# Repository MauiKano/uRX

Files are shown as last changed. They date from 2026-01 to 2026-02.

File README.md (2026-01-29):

Hybrid NAVTEX & Wideband Receiver (ESP32 + Tayloe Mixer + Si4732)
Overview
This project is a high-performance, dual-path radio receiver designed for the ESP32 platform. It combines a traditional digital "Radio-on-a-Chip" (Si4732) with a high-sensitivity, software-defined Tayloe Quadrature Product Detector (QPD). The design is specifically optimized for the reception and decoding of NAVTEX signals at 518 kHz, utilizing a professional-grade analog signal chain and high-resolution external ADCs.
Key Features
1. Dual Receiver Architecture

    Path A (SDR): A high-linearity Tayloe Mixer (using the CBT3253 bus switch) for I/Q sampling. This path is intended for precision DSP decoding of weak digital modes like NAVTEX.
    Path B (Digital): An Si4732-A10 all-in-one receiver for general-purpose listening (AM/FM/SW/LW) and RDS data acquisition.

2. High-End Analog Signal Chain

    Active Antenna Splitter: An OPA2690 high-speed current-feedback op-amp serves as an active buffer/splitter, providing high isolation between the two receiver paths without signal loss.
    Post-Mixer Amplification: A LM4562 ultra-low noise, high-fidelity audio operational amplifier provides 33.4 dB of gain (Gain=47) to the I/Q signals.
    Optimized Filtering: Integrated active low-pass filtering with a 2.8 kHz cutoff, specifically tuned to maximize the SNR for NAVTEX/SITOR-B signals.
    Ultra-Stable Reference: A precision LM4040 (2.5V) shunt reference provides a clean virtual ground for the analog stages, ensuring maximum dynamic range and rejection of power supply noise.

3. Precision Clocking & Digitization

    Clock Generation: An Si5351A triple clock generator provides the quadrature sampling clock for the Tayloe mixer and a dedicated low-jitter master clock for the ADC.
    External ADC: Instead of the noisy internal ESP32 ADC, this design uses the PCM1808 (24-bit, 99dB SNR). It interfaces via I2S, providing a transparent digital stream to the ESP32 for software demodulation.

4. EMI/EMC Optimized Layout

    Power Isolation: Independent Ferrite Bead filtering for every major IC to prevent digital switching noise from the ESP32 and Si5351 from polluting the analog front-end.
    Ground Management: Strict separation of analog and digital ground paths, joined at a single star-point under the ADC to minimize ground loops.

Technical Specifications

    Primary Frequency: 518 kHz (NAVTEX)
    Mixer Type: Quadrature Sampling Detector (Tayloe)
    ADC Resolution: 24-Bit I2S (PCM1808)
    Processor: ESP32 (Dual-Core 240 MHz)
    I/Q Bandwidth: ~3 kHz (Optimized for digital modes)

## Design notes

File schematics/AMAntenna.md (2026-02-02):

# uRX Antenna Subsystem: Navtex Dual-Band Ferrite Antenna

This document specifies the design and construction of the high-performance magnetic loopstick antenna for the **uRX** handheld receiver, optimized for **490 kHz** and **518 kHz** Navtex reception.

## Technical Specifications

| Parameter | Specification | Notes |
|---|---|---|
| **Primary Frequency** | 518 kHz | International Navtex (English) |
| **Secondary Frequency** | 490 kHz | Local Navtex (National languages) |
| **Antenna Type** | High-Q Magnetic Loopstick  | Optimized for MF (Medium Frequency) |
| **Target Inductance** | 330 µH | Matches [Si4732 AMI](https://www.silabs.com) requirements |
| **Rod Material** | NiZn Ferrite (Mix 61) | Low-loss at 500 kHz ([Fair-Rite Type 61](https://fair-rite.com)) |
| **Rod Dimensions** | 10 mm x 80 mm | Balanced for handheld portability |
| **Conductor Type** | 40/46 Litz Wire | Minimizes skin effect, ensures high Q |

## Winding & Construction

To achieve the target inductance of **330 µH** on the specified 10 mm rod, follow these construction steps:

*   **Turn Count:** Approximately **66 turns** (single-layer solenoid).
*   **Winding Method:** Wind the Litz wire tightly on a movable paper or plastic sleeve.
*   **Inductance Tuning:** Slide the coil toward the center of the rod to increase inductance, or toward the ends to decrease it.
*   **Resonance Tuning:**
    *   **Band Center:** 504 kHz.
    *   **Fixed Capacitor:** 270 pF (**NP0/C0G** dielectric for thermal stability).
    *   **Trimmer:** 10–60 pF parallel trimmer for fine-tuning the peak resonance.

## Interface & System Integration

*   **Buffer Stage:** The antenna feeds the [Texas Instruments OPA2211](https://www.ti.com) (U11).
*   **Input Impedance ($Z_{in}$):** Maintained at **100 kΩ** via the bias resistor (**R2**) to prevent damping of the tuned circuit.
*   **Isolation:** The dual-opamp configuration provides independent signal paths for the **Tayloe Mixer** and the **Si4732** tuner, preventing local oscillator (LO) leakage.
*   **Expected Performance:** A Q-factor of **>150**, providing excellent narrowband selectivity and rejection of out-of-band noise (e.g., from the ESP32-C3 digital lines).

---
*Documentation generated for the uRX Project - 2026*

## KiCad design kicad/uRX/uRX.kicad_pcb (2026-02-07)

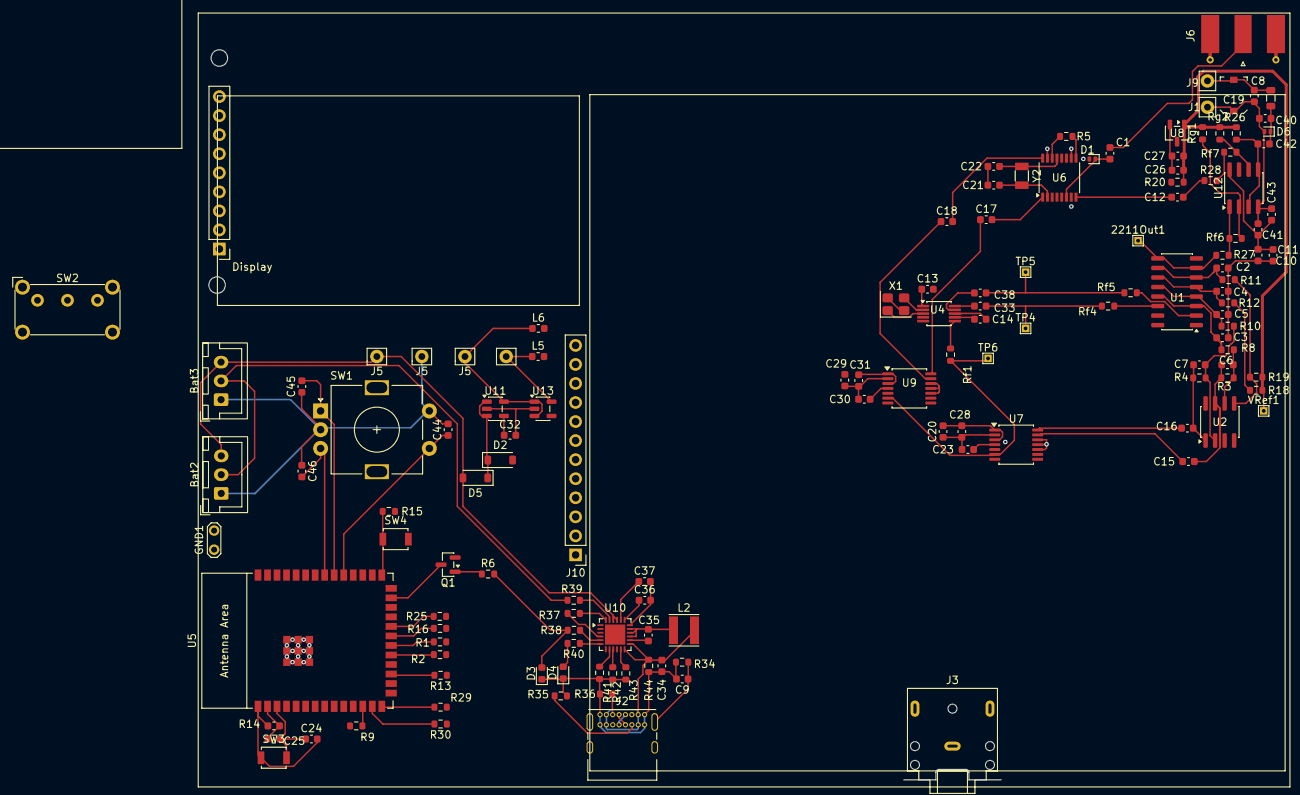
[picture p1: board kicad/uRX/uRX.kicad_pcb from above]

Board: 2 copper layers, 142 parts (0 on the bottom side), 91 nets.

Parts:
2211Out1: TestPoint; TestPoint_THTPad_1.0x1.0mm_Drill0.5mm
Bat2, Bat3: JST-XH; JST_XH_B3B-XH-A_1x03_P2.50mm_Vertical
C1, C40: 100p; C_0603_1608Metric
C2, C3, C4, C5: 220n; C_0603_1608Metric
C6, C7: 1.2n; C_0603_1608Metric
C8: 270p; C_0603_1608Metric
C9: 4.7n; C_0603_1608Metric
C10, C41: 2.2u; C_0603_1608Metric
C11, C12, C13, C14, C23, C26, C28, C30, C31, C35, C42, C43, C44, C45, C46: 100n; C_0603_1608Metric
C15, C16, C17, C18: 4.7u; C_0603_1608Metric
C19: 10p-60p; C_Trimmer_Murata_TZC3
C20, C27, C29, C34, C36, C37: 10u; C_0603_1608Metric
C21, C22: 22p; C_0603_1608Metric
C24: 1u; C_0603_1608Metric
C25: 47u; C_0603_1608Metric
C32, C33, C38: 10n; C_0603_1608Metric
D1, D6: PESD5V0L1ULD; D_SOD-882D
D2, D5: D_Schottky; D_SOD-123
D3, D4: LED_Small; LED_0603_1608Metric
Display: PinHeader_1x09_P2.54mm_Vertical
GND1: TestPoint_2Pole; TestPoint_2Pads_Pitch2.54mm_Drill0.8mm
J1: RF_AM_GND; Pin_D0.9mm_L10.0mm_W2.4mm_FlatFork
J2: C165948; USB_C_Receptacle_GCT_USB4085
J3: AudioJack2_Ground; Jack_3.5mm_CUI_SJ1-3523N_Horizontal
J5, J5#4: +5V; Pin_D0.9mm_L10.0mm_W2.4mm_FlatFork
J5#2: GND; Pin_D0.9mm_L10.0mm_W2.4mm_FlatFork
J5#3: Bat; Pin_D0.9mm_L10.0mm_W2.4mm_FlatFork
J6: U.FL; SMA_Molex_73251-1153_EdgeMount_Horizontal
J9: RF_AM__In; Pin_D0.9mm_L10.0mm_W2.4mm_FlatFork
J10: GPIO_A; PinHeader_1x12_P2.54mm_Vertical
L2: 2.2uH,3A; L_Taiyo-Yuden_NR-40xx
L4: 1uH,50mA; L_0805
L5, L6: Ferrite_perl; L_0603_1608Metric
M2, M2#2, M2#3, M2#4, M2#5, M2#6, M2#7: MountingHole_2.2mm_M2_DIN965
Q1: BC847; SOT-23
R1, R2, R16, R25, R27, R28, R29, R30: 22; R_0603_1608Metric
R3, R4, R18, R19: 47k; R_0603_1608Metric
R5, R14, R15: 10k; R_0603_1608Metric
R6: 10K; R_0603_1608Metric
R8, R10, R11, R12, R20: 1k; R_0603_1608Metric
R9, R13: 4.7K; R_0603_1608Metric
R26: 100k; R_0603_1608Metric
R34: 1M; R_0603_1608Metric
R35, R36, R44: 5.1K; R_0603_1608Metric
R37: 33k; R_0603_1608Metric
R38, R39, R40: 100; R_0603_1608Metric
R41, R42: 120K; R_0603_1608Metric
R43: 75k; R_0603_1608Metric
Rf1, Rf4, Rf5: 47; R_0603_1608Metric
Rf6, Rf7: 604; R_0603_1608Metric
Rg1, Rg2: 604; R_0603_1608Metric
SW1: RotaryEncoder_Switch; RotaryEncoder_Alps_EC11E-Switch_Vertical_H20mm
SW2: SW_DPDT_x2; SW_E-Switch_EG1224_SPDT_Angled
SW3: Reset; SW_SPST_B3U-1000P
SW4: Boot; SW_SPST_B3U-1000P
TP4: CLK0; TestPoint_THTPad_1.0x1.0mm_Drill0.5mm
TP5: CLK1; TestPoint_THTPad_1.0x1.0mm_Drill0.5mm
TP6: CLK2; TestPoint_THTPad_1.0x1.0mm_Drill0.5mm
U1: CBT3253; SO-16_3.9x9.9mm_P1.27mm
U2: LM4562; SOIC-8_3.9x4.9mm_P1.27mm
U4: Si5351A-B-GT; MSOP-10_3x3mm_P0.5mm
U5: ESP32-S3-WROOM-2
U6: Si4732-A10; SSOP-16_3.9x4.9mm_P0.635mm
U7, U9: PCM1808PWR; TSSOP-14_4.4x5mm_P0.65mm
U8: LM4040-2.5; SOT-23-3
U10: IP2326; QFN-24-1EP_4x4mm_P0.5mm_EP2.7x2.7mm
U11: LP2985-5.0; SOT-23-5
U12: OPA2211; SOIC-8_3.9x4.9mm_P1.27mm
U13: HT733333; SOT-23-5
VRef1: VRef; TestPoint_THTPad_1.0x1.0mm_Drill0.5mm
X1: X322525MOB4SI; Crystal_SMD_3225-4Pin_3.2x2.5mm
Y2: 32768kHz; Crystal_SMD_3215-2Pin_3.2x1.5mm

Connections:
+3.3V: C13.1, C14.1, C25.1, C30.2, J5.1, J10.10, L5.1, R5.1, R9.1, R13.1, R14.1, R15.1, U4.1 (VDD), U4.7 (VDDO), U5.2 (3V3), U6.14 (VDD), U9.4 (VDD), U13.5 (VOUT)
+3.3Vfiltered: C23.2, U7.4 (VDD)
+5V: C29.2, C31.2, J10.9, L6.1, SW2.2 (B), U9.1 (VREF), U9.3 (VCC), U13.1 (VIN), U13.3 (EN)
+5Vfiltered: C10.1, C11.1, C20.2, C28.2, C41.1, C43.1, R20.2, U1.16 (VCC), U7.1 (VREF), U7.3 (VCC), U12.8 (V+)
+VBatt: Bat2.3, Bat3.3, D5.2 (A), J5#3.1, U10.21 (VOUT), U10.22 (VOUT)
/I2S0_DOUT: J10.6, R16.1, U7.9 (DOUT)
/I2S1_DOUT: J10.7, R25.1, U9.9 (DOUT)
/I2S_BCK: J10.4, R1.1, U7.8 (BCK), U9.8 (BCK)
/I2S_LRCK: J10.5, R2.1, U7.7 (LRCK), U9.7 (LRCK)
/SCL: J10.2, R13.2, U4.4 (SCL), U5.17 (GPIO9/TOUCH9/ADC1_CH8/FSPIHD/SUBSPIHD), U6.11 (SCLK)
/SDA: J10.1, R9.2, U4.5 (SDA), U5.12 (GPIO8/TOUCH8/ADC1_CH7/SUBSPICS1), U6.12 (SDIO)
/VRev2.5: C26.1, C27.1, R18.2, R19.2, R20.1, R26.2, Rg1.2, Rg2.1, U8.1 (K), VRef1.1
ADC_SCKI: J10.3, Rf1.1, TP6.1, U5.18 (GPIO10/TOUCH10/ADC1_CH9/FSPICS0/FSPIIO4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), U7.6 (SCKI), U9.6 (SCKI)
Earth: D1.2 (A), U6.7 (RFGND)
GND: Bat2.1, Bat3.1, C2.2, C3.2, C4.2, C5.2, C8.2, C9.2, C10.2, C11.2, C13.2, C14.2, C19.1, C20.1, C21.1, C22.1, C23.1, C24.2, C25.2, C26.2, C27.2, C28.1, C29.1, C30.1, C31.1, C32.2, C34.2, C36.2, C37.2, C40.2, C41.2, C43.2, C44.2, C45.1, C46.1, D3.1 (K), D4.1 (K), D6.2 (A), Display.1, GND1.1, GND1.2, J1.1, J2.A1 (GND), J2.A12 (GND), J2.B1 (GND), J2.B12 (GND), J5#2.1, J6.2 (Ext), Q1.2 (E), R34.2, R35.2, R36.2, R37.2, R41.2, R42.2, R43.2, R44.2, SW1.C, SW1.S2, SW3.1, SW4.2, U1.1 (1~OE), U1.8 (GND), U1.15 (2~OE), U4.8 (GND), U5.1 (GND), U5.40 (GND), U5.41 (GND), U6.10 (SENB), U6.15 (GND), U7.2 (AGND), U7.5 (DGND), U7.10 (MD0), U7.11 (MD1), U7.12 (FMT), U8.2 (A), U9.2 (AGND), U9.5 (DGND), U9.10 (MD0), U9.11 (MD1), U9.12 (FMT), U10.18 (PGND), U10.24 (VBAT_GND), U11.2 (GND), U12.4 (V-), U13.2 (GND), X1.2 (GND), X1.4 (GND)
unnamed: Bat2.2, Bat3.2, R39.2
unnamed: C12.1, R28.1
unnamed: C6.2, C15.1, R3.1, U2.7
unnamed: C7.2, C16.1, R4.1, U2.1
unnamed: C33.2, Rf4.2, TP4.1
unnamed: C35.1, L2.1, U10.15 (LX), U10.16 (LX), U10.17 (LX)
unnamed: C36.1, U10.19 (VSYS)
unnamed: C37.1, U10.20 (VSYS)
unnamed: C38.2, Rf5.2, TP5.1
unnamed: C42.1, R26.1, U12.3 (+), U12.5 (+)
unnamed: C1.1, D1.1 (K), U6.6 (FMI)
unnamed: D2.1 (K), D5.1 (K), U11.1 (VIN), U11.3 (ON/~OFF)
unnamed: D3.2 (A), R6.2, R38.2
unnamed: D4.2 (A), R40.2
unnamed: C40.1, C42.2, D6.1 (K), L4.1
unnamed: J2.A5 (CC1), R36.1
unnamed: J2.B5 (CC2), R35.1
unnamed: C9.1, J2.S1 (SHIELD), R34.1
unnamed: C1.2, J6.1 (In)
unnamed: C8.1, C19.2, J9.1, L4.2
unnamed: Q1.1 (B), R6.1
unnamed: R27.2, Rf6.1, U12.1
unnamed: R28.2, Rf7.1, U12.7
unnamed: Rf6.2, Rg1.1, U12.2 (-)
unnamed: Rf7.2, Rg2.2, U12.6 (-)
unnamed: SW2.1 (A), U11.5 (VOUT)
unnamed: 2211Out1.1, R27.1, U1.7 (1A), U1.9 (2A)
unnamed: C2.1, R11.2, U1.6 (1B1), U1.10 (2B1)
unnamed: C4.1, R12.2, U1.5 (1B2), U1.11 (2B2)
unnamed: C5.1, R10.2, U1.4 (1B3), U1.12 (2B3)
unnamed: C3.1, R8.2, U1.3 (1B4), U1.13 (2B4)
unnamed: Rf4.1, U1.14 (S0)
unnamed: Rf5.1, U1.2 (S1)
unnamed: R12.1, R18.1, U2.3 (+)
unnamed: C7.1, R4.2, R10.1, U2.2 (-)
unnamed: R11.1, R19.1, U2.5 (+)
unnamed: C6.1, R3.2, R8.1, U2.6 (-)
unnamed: C33.1, U4.10 (CLK0)
unnamed: C38.1, U4.9 (CLK1)
unnamed: Rf1.2, U4.6 (CLK2)
unnamed: U4.2 (XA), X1.3 (OSC)
unnamed: U4.3 (XB), X1.1 (OSC)
unnamed: C24.1, R14.2, SW3.2, U5.3 (EN)
unnamed: R15.2, SW4.1, U5.27 (GPIO0/BOOT)
unnamed: R1.2, U5.19 (GPIO11/TOUCH11/ADC2_CH0/FSPID/FSPIIO5/S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)
unnamed: R2.2, U5.20 (GPIO12/TOUCH12/ADC2_CH1/FSPICLK/FSPIIO6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)
unnamed: R16.2, U5.21 (GPIO13/TOUCH13/ADC2_CH2/FSPIQ/FSPIIO7/S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)
unnamed: R25.2, U5.22 (GPIO14/TOUCH14/ADC2_CH3/FSPIWP/FSPIDQS/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)
unnamed: R30.2, U5.13 (GPIO19/U1RTS/ADC2_CH8/CLK_OUT2/USB_D-)
unnamed: R29.2, U5.14 (GPIO20/U1CTS/ADC2_CH9/CLK_OUT1/USB_D+)
unnamed: C44.1, SW1.S1, U5.31 (GPIO38/FSPIWP/SUBSPIWP)
unnamed: C45.2, SW1.A, U5.32 (MTCK/GPIO39/CLK_OUT3/SUBSPICS1)
unnamed: C46.2, SW1.B, U5.33 (MTDO/GPIO40/CLK_OUT2)
unnamed: C12.2, U6.8 (AMI)
unnamed: C21.2, U6.2 (DClk), Y2.1
unnamed: C17.2, U6.1 (LOut)
unnamed: C22.2, U6.13 (RCLK), Y2.2
unnamed: C18.2, U6.16 (ROut)
unnamed: C15.2, U7.13 (VINL)
unnamed: C16.2, U7.14 (VINR)
unnamed: C18.1, J3.S, U9.13 (VINL)
unnamed: C17.1, J3.T, U9.14 (VINR)
unnamed: R38.1, U10.5 (BAT_STAT)
unnamed: C35.2, U10.14 (BST)
unnamed: R41.1, U10.8 (VIN_UVSET), U10.25 (GND)
unnamed: R43.1, U10.11 (ISET)
unnamed: R40.1, U10.6 (LED)
unnamed: R37.1, U10.4 (NTC)
unnamed: R39.1, U10.23 (VBATM)
unnamed: R42.1, U10.9 (VIN_OVSET)
unnamed: C32.1, U11.4 (BP)
Q_BAT_STAT: Q1.3 (C), U5.25 (GPIO48/SPICLK_N/SUBSPICLK_N_DIFF)
RST_4732: J10.8, R5.2, U5.23 (GPIO21), U6.9 (RST)
USB_D+: J2.A6 (D+), J2.B6 (D+), R29.1
USB_D-: J2.A7 (D-), J2.B7 (D-), R30.1
VBUS: C34.1, D2.2 (A), J2.A4 (VBUS), J2.A9 (VBUS), J2.B4 (VBUS), J2.B9 (VBUS), L2.2, R44.1, U10.12 (EN), U10.13 (VIN)

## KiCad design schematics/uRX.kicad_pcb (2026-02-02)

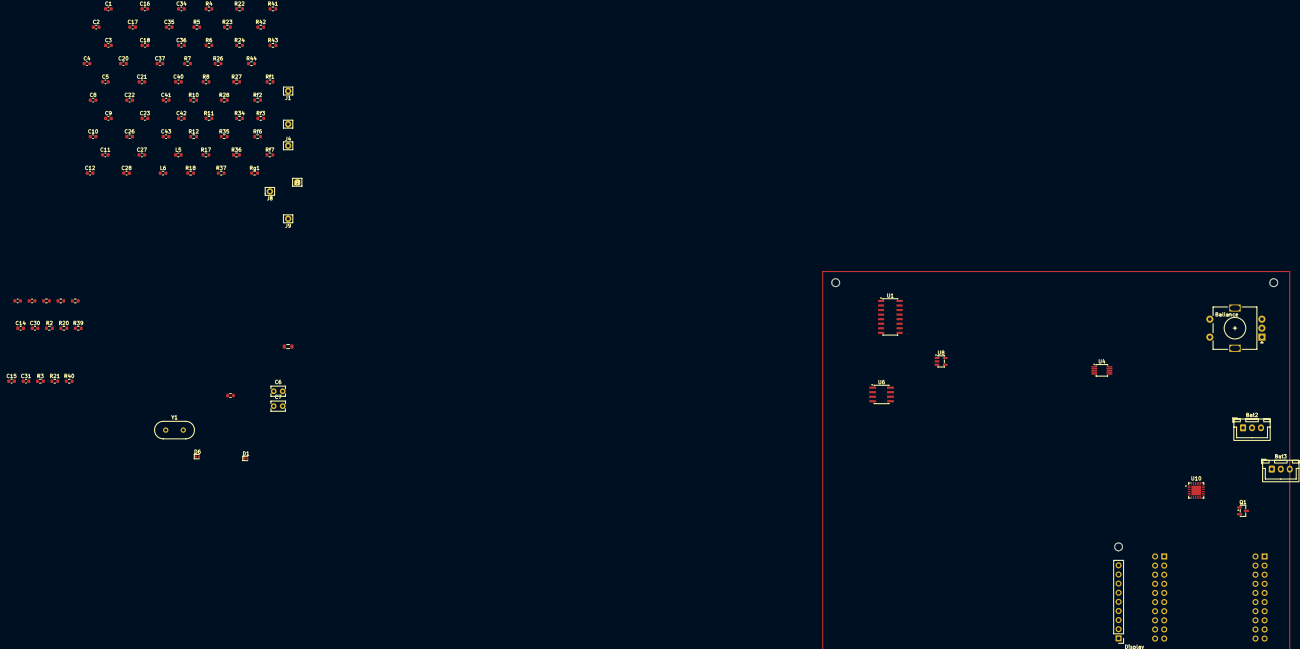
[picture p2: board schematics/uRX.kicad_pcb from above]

Board: 2 copper layers, 103 parts (0 on the bottom side), 59 nets, no tracks yet.

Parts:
Bat2, Bat3: JST-XH; JST_XH_B3B-XH-A_1x03_P2.50mm_Vertical
C1, C40: 100p; C_0603_1608Metric
C2, C3, C4, C5: 220n; C_0603_1608Metric
C6, C7: 1.2n; C_Disc_D3.8mm_W2.6mm_P2.50mm
C8: 270p; C_0603_1608Metric
C9: 4.7n; C_0603_1608Metric
C10, C41: 2.2u; C_0603_1608Metric
C11, C12, C23, C26, C28, C30, C31, C35, C42, C43: 100n; C_0603_1608Metric
C13, C14: 2..20p; C_0603_1608Metric
C15, C16, C17, C18: 4.7u; C_0603_1608Metric
C20, C27, C29, C34, C36, C37: 10u; C_0603_1608Metric
C21, C22: 22p; C_0603_1608Metric
D1, D6: PESD5V0L1ULD; D_SOD-882D
Display: PinHeader_1x09_P2.54mm_Vertical
J1: RF_GMD; Pin_D0.9mm_L10.0mm_W2.4mm_FlatFork
J4: +5Vfiltered; Pin_D0.9mm_L10.0mm_W2.4mm_FlatFork
J5: +5V; Pin_D0.9mm_L10.0mm_W2.4mm_FlatFork
J7: +3.3Vfiltered; Pin_D0.9mm_L10.0mm_W2.4mm_FlatFork
J8, J9: RF_In; Pin_D0.9mm_L10.0mm_W2.4mm_FlatFork
L4: 1uH,50mA; L_0805
L5, L6: Ferrite_perl; L_0603_1608Metric
M2, M2#2, M2#3, M2#4, M2#5, M2#6: MountingHole_2.2mm_M2_DIN965
Q1: BC847; SOT-23
R1, R2, R21, R22, R23, R24, R27, R28: 22; R_0603_1608Metric
R3, R4, R18, R19: 47k; R_0603_1608Metric
R5: 10k; R_0603_1608Metric
R6: 10K; R_0603_1608Metric
R7, R17: 4.7kΩ; R_0603_1608Metric
R8, R10, R11, R12, R20: 1k; R_0603_1608Metric
R26: 100k; R_0603_1608Metric
R34: 1M; R_0603_1608Metric
R35, R36, R44: 5.1K; R_0603_1608Metric
R37: 33k; R_0603_1608Metric
R38, R39, R40: 100; R_0603_1608Metric
R41, R42: 120K; R_0603_1608Metric
R43: 75k; R_0603_1608Metric
Rf1: 33; R_0603_1608Metric
Rf2, Rf3: 47; R_0603_1608Metric
Rf6, Rf7: 604; R_0603_1608Metric
Rg1, Rg2: 604; R_0603_1608Metric
U1: CBT3253; SO-16_3.9x9.9mm_P1.27mm
U4: Si5351A-B-GT; MSOP-10_3x3mm_P0.5mm
U6: Si4732-A10; SOIC-8_3.9x4.9mm_P1.27mm
U8: LM4040-2.5; SOT-23-5
U10: IP2326; QFN-24-1EP_4x4mm_P0.5mm_EP2.7x2.7mm
Y1: 25MHz; Crystal_HC49-U_Vertical

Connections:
+3.3V: L5.1, R7.1, R17.1, U4.1 (VDD), U4.7 (VDDO)
+3.3Vfiltered: C23.2, C30.2, R5.1
+5V: Bat2.3, Bat3.3, L6.1, U10.21 (VOUT), U10.22 (VOUT)
+5Vfiltered: C10.1, C11.1, C20.2, C28.2, C29.2, C31.2, C41.1, C43.1, R20.2, U1.16 (VCC)
/SCL: R17.2, U4.4 (SCL)
/SDA: R7.2, U4.5 (SDA)
/VRev2.5: C26.1, C27.1, R18.2, R19.2, R20.1, R26.2, Rg1.2, Rg2.1, U8.4 (K)
Earth: D1.2 (A), U6.7 (RFGND)
GND: Bat2.1, Bat3.1, C2.2, C3.2, C4.2, C5.2, C8.2, C9.2, C10.2, C11.2, C13.2, C14.2, C20.1, C21.1, C22.1, C23.1, C26.2, C27.2, C28.1, C29.1, C30.1, C31.1, C34.2, C36.2, C37.2, C40.2, C41.2, C43.2, D6.2 (A), Display.1, J1.1, Q1.2 (E), R34.2, R35.2, R36.2, R37.2, R41.2, R42.2, R43.2, R44.2, U1.1 (1~OE), U1.8 (GND), U1.15 (2~OE), U4.8 (GND), U8.5 (A), U10.18 (PGND), U10.24 (VBAT_GND)
unnamed: Bat2.2, Bat3.2, R39.2
unnamed: C12.1, R28.1
unnamed: C6.2, C15.1, R3.1
unnamed: C7.2, C16.1, R4.1
unnamed: C35.1, U10.16 (LX)
unnamed: C36.1, U10.19 (VSYS)
unnamed: C37.1, U10.20 (VSYS)
unnamed: C42.1, R26.1
unnamed: C1.1, D1.1 (K), U6.6 (FMI)
unnamed: R6.2, R38.2
unnamed: C40.1, C42.2, D6.1 (K), L4.1
unnamed: C9.1, R34.1
unnamed: J4.1, L6.2
unnamed: J7.1, L5.2
unnamed: C1.2, J8.1
unnamed: C8.1, J9.1, L4.2
unnamed: Q1.1 (B), R6.1
unnamed: R27.2, Rf6.1
unnamed: R28.2, Rf7.1
unnamed: Rf6.2, Rg1.1
unnamed: Rf7.2, Rg2.2
unnamed: R27.1, U1.7 (1A), U1.9 (2A)
unnamed: C2.1, R11.2, U1.6 (1B1), U1.10 (2B1)
unnamed: C4.1, R12.2, U1.5 (1B2), U1.11 (2B2)
unnamed: C5.1, R10.2, U1.4 (1B3), U1.12 (2B3)
unnamed: C3.1, R8.2, U1.3 (1B4), U1.13 (2B4)
unnamed: Rf3.1, U1.14 (S0)
unnamed: Rf2.1, U1.2 (S1)
unnamed: R12.1, R18.1
unnamed: C7.1, R4.2, R10.1
unnamed: R11.1, R19.1
unnamed: C6.1, R3.2, R8.1
unnamed: Rf3.2, U4.10 (CLK0)
unnamed: Rf2.2, U4.9 (CLK1)
unnamed: Rf1.2, U4.6 (CLK2)
unnamed: C13.1, U4.2 (XA), Y1.2
unnamed: C14.1, U4.3 (XB), Y1.1
unnamed: C12.2, U6.8 (AMI)
unnamed: C21.2, U6.2 (DClk)
unnamed: C17.2, U6.1 (LOut)
unnamed: R38.1, U10.5 (BAT_STAT)
unnamed: C35.2, U10.14 (BST)
unnamed: C34.1, R44.1, U10.12 (EN), U10.13 (VIN)
unnamed: R41.1, U10.8 (VIN_UVSET), U10.25 (GND)
unnamed: R43.1, U10.11 (ISET)
unnamed: R40.1, U10.6 (LED)
unnamed: U10.15 (LX), U10.17 (LX)
unnamed: R37.1, U10.4 (NTC)
unnamed: R39.1, U10.23 (VBATM)
unnamed: R42.1, U10.9 (VIN_OVSET)

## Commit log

2026-01-29 schematics finalization
    [uRX.kicad_sch]
2026-01-30 add usb power
    [uRX.kicad_sch]
2026-01-31 finalize power circuit
    [charger.kicad_sch, uRX.kicad_sch]
2026-01-31 add power to the rest
    [charger.kicad_sch, uRX.kicad_sch]
2026-01-31 gpio to vbat_stat
    [uRX.kicad_sch]
2026-02-01 use opa2211 in AM Antenna input
    [uRX.kicad_sch]
2026-02-02 start pcb
    [adc.kicad_sch, tayloe.kicad_sch, uRX.kicad_pcb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]
2026-02-03 resolve missing footprints
    [uRX.kicad_pcb]
2026-02-04 add esp32 to pcb
    [esp32Part.kicad_sch, uRX.kicad_pcb, uRX.kicad_sch]
2026-02-05 work on rf frontend and battery charger
    [uRX.kicad_pcb, uRX.kicad_sch]
2026-02-06 work on rf part pcb
    [uRX.kicad_pcb]
2026-02-07 finalize rf, 4732 and clock
    [uRX.kicad_pcb, uRX.kicad_sch]
2026-02-07 connect all together, v0
    [uRX.kicad_pcb]
